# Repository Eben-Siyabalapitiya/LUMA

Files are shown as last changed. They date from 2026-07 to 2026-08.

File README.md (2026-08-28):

# LUMA 

A tiny desk robot I built that actually has a personality. Runs on an ESP32, shows animated eyes on a 1.8" TFT screen, and reacts to how you touch it. It also pulls live weather, keeps time, and has a calendar, all sitting on your desk just vibing.

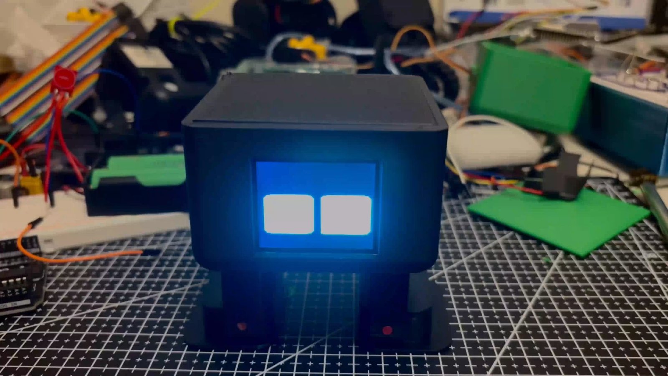
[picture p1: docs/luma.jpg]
LUMA on my desk


I made LUMA because my desk felt empty and I randomly got the urge to build a robot. That was pretty much the whole reason.

---

## What it does

LUMA has four screens you cycle through by tapping a touch sensor:

- **Face mode** : animated robot eyes that blink, look around, and randomly switch expressions
- **Clock** : clean digital clock synced over WiFi via NTP
- **Weather** : live temp, condition, humidity, and wind from OpenWeatherMap
- **Calendar** : full month grid with event highlights and floating particles in the background

The second touch sensor controls emotions:

| Interaction | What happens | 
|---|---|
| Single tap | LUMA gets excited : big happy eyes, fast blinks |
| Spam tap (4+) | LUMA gets mad : flat angry red eyes, multiple variants |
| Hold ~1 second | LUMA gets cozy : drowsy droopy eyes, slow blinks |
| Leave it alone | Resets to default after 6 seconds |

Each emotion has multiple face variants picked using weighted random probabilities so you never see the exact same reaction twice. After 30 seconds of no interaction on any screen it automatically goes back to face mode.

---

## Libraries needed

Install all of these through Arduino IDE Library Manager:

- Adafruit GFX Library
- Adafruit ST7735 and ST7789 Library
- TFT_RoboEyes by Shourov Paul

---

## Quick setup

1. Clone this repo or download the ZIP
2. Open `LUMA_v3.ino` in Arduino IDE
3. Fill in your details at the top:

```cpp
const char* ssid       = "YOUR_WIFI";
const char* password   = "YOUR_PASSWORD";
const char* weatherKey = "YOUR_OPENWEATHER_KEY";
```

4. Select **ESP32 Dev Module** as your board
5. Upload

Get a free OpenWeather API key at [openweathermap.org](https://openweathermap.org) — new keys take up to 2 hours to activate so grab one early.

---

## Project Files

- [`LUMA_v3.ino`](LUMA_v3.ino) : the firmware
- [`BOM.csv`](BOM.csv) / [`BOM.md`](BOM.md) : full parts list with links and rough CAD prices
- [`docs/WIRING.md`](docs/WIRING.md) : wiring diagram plus a pin-by-pin table for the TFT and both touch sensors
- [`CAD/`](CAD/README.md) : the printed enclosure : STEP files for every part, the `LUMA_V3.3mf` print file, and the Onshape link

[meetluma.live](https://www.meetluma.live/) is the main hub for all of it : full parts list,
the wiring diagram with the visual schematic, the CAD files through Onshape, the 3MF print
files, and the step-by-step assembly guide.

---

## Full Build Guide

Parts list, wiring diagram, 3D files, step-by-step assembly, and everything else you need to build your own LUMA:

**[meetluma.live](https://www.meetluma.live/)**

---

## Stardance

Built for Hack Club Stardance : <https://stardance.hackclub.com/projects/14705>

---
## AI Usage
Used AI as a guide when things got overwhelming like when my firmware hit the flash limit and I had no idea where to start. It never built anything for me, just helped me figure out what was wrong when I was stuck. Everything was built and decided by me.

---

Built by Eben Siyabalapitiya

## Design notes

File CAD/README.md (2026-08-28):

# CAD

The LUMA enclosure was designed in Onshape.

## STEP files (the CAD model)

Exported from Onshape.

- `LUMA_ASSEMBLY.step` : the whole thing assembled
- `Brain.step` : main body that holds the ESP32 and screen
- `Top_cover.step` : lid
- `Legs.step` : the legs
- `Leg_Joint.step` : pin that joins the legs to the body
- `Feet.step` : the feet

## Print file

- `LUMA_V3.3mf` : print-ready, opens in Bambu Studio, PrusaSlicer or Cura with the plate and
  settings already set up. Single colour, no supports needed on the body.

## Source

Live Onshape document (public, view or make your own copy to change the fit, screen cutout,
base size, etc.):
<https://cad.onshape.com/documents/46f7879e5381e394e69948ae/w/efe1e75b1016428808b3d0a2/e/479ee3b72502e2ef5b15629c>

Same files and the full print/assembly walkthrough are on [meetluma.live](https://www.meetluma.live/build).

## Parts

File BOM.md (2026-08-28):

# Bill of Materials

Machine-readable version with links: [`BOM.csv`](BOM.csv).

Prices are what I actually see on Amazon.ca (Aug 2026), in CAD, before tax and shipping.
They move around a lot and everything is cheaper on AliExpress if you're willing to wait.

| Part | Qty | Amazon.ca price (CAD) |
|---|---|---|
| ESP32 dev board, WROOM-32, 30-pin, USB-C | 1 | ~$14 |
| DIYmalls 1.8" ST7735S TFT LCD (128x160 SPI) | 1 | ~$15 single, ~$21 for a 2-pack |
| TTP223 capacitive touch sensor | 2 | only sold in packs, ~$13 for 20 |
| 830-point solderless breadboard | 1 | ~$8 single, ~$13 for a 3-pack |
| Dupont jumper wires, 120 pcs (M-M / M-F / F-F) | 1 kit | ~$9 |
| USB-C data cable | 1 | ~$8 |
| ESP32 30-pin breakout board (optional, expands 1 GPIO to 2, easier than a breadboard) | 1 | ~$10, sold ~$19 for a 2-pack |

Rough totals:

- Core electronics (ESP32 + screen + touch sensors): **~$42-45**
- Add breadboard, jumper wires and a USB-C cable: **~$65-70**
- Most of the extras (breadboard, wires, cable) you probably already have.

You'll also need a bit of filament for the printed case and a free OpenWeatherMap API key.

Full parts list with links and the rest of the build guide: [meetluma.live](https://www.meetluma.live/).

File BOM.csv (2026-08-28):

Part | Qty | Unit Price CAD | Link | Notes
ESP32 dev board WROOM-32 (30-pin USB-C) | 1 | 14 | https://www.amazon.ca/dp/B0CHBMFJBQ | Main board. "ESP32 Dev Module" in Arduino IDE
DIYmalls 1.8" ST7735S TFT LCD 128x160 SPI | 1 | 15 | https://www.amazon.ca/dp/B0BFDQDGSQ | ~$21 for a 2-pack: https://www.amazon.ca/dp/B0C2HNVSWV
TTP223 capacitive touch sensor | 2 | 0.65 | https://www.amazon.ca/dp/B01D1D0FLG | Sold in packs, ~$13 for 20 (HiLetgo). Need 2
830-point solderless breadboard | 1 | 8 | https://www.amazon.ca/s?k=830+point+solderless+breadboard | ~$13 for a 3-pack (ELEGOO)
Dupont jumper wires 120 pcs (M-M / M-F / F-F) | 1 | 9 | https://www.amazon.ca/dp/B0HGB3P9WG | 20 cm length
USB-C data cable | 1 | 8 | https://www.amazon.ca/s?k=usb-c+data+cable | Power and flashing
ESP32 30-pin breakout board | 1 | 10 | https://www.amazon.ca/dp/B0CWL7TK7T | Optional. Expands 1 GPIO to 2, easier than a breadboard. ~$19 for a 2-pack

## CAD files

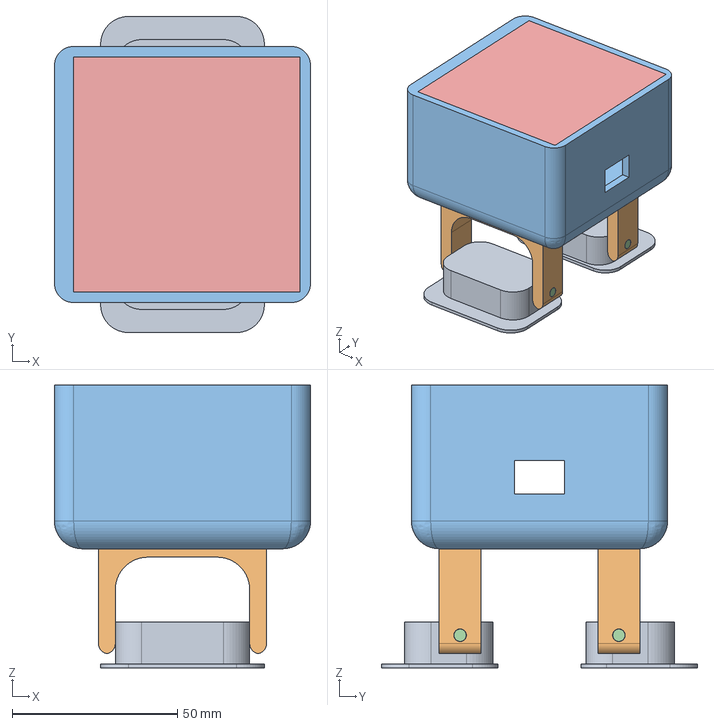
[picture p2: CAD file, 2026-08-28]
CAD/LUMA_ASSEMBLY.step
77.5 x 95.6 x 85.6 mm

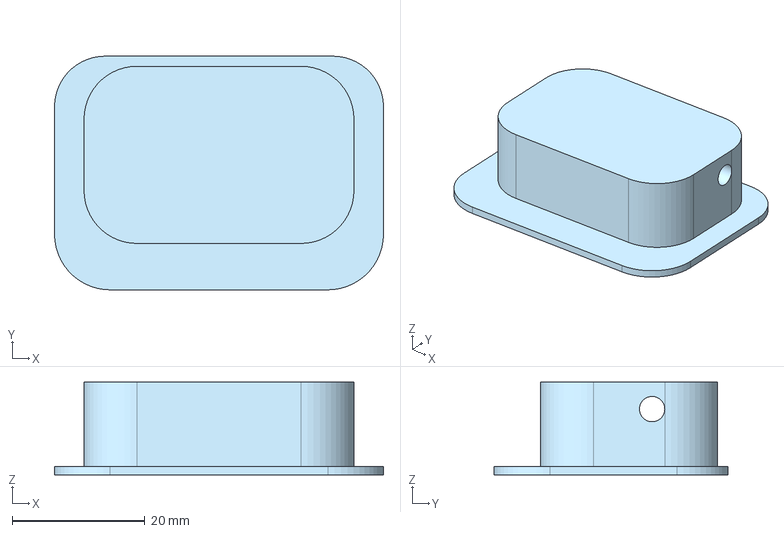
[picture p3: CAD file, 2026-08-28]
CAD/Feet.step
49.5 x 35.2 x 14.0 mm

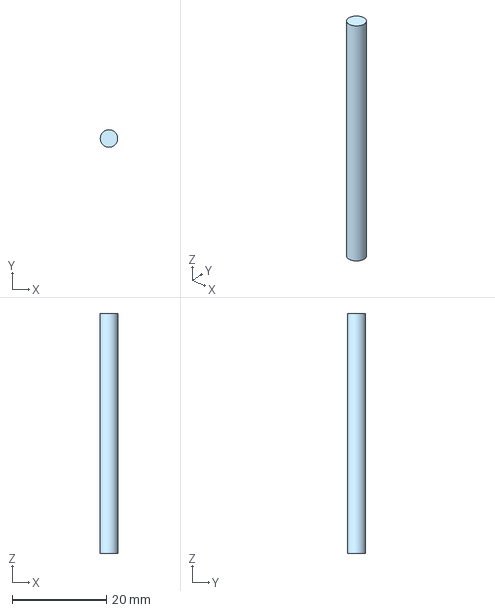
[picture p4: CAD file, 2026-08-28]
CAD/Leg_Joint.step
3.70 x 3.71 x 50.8 mm

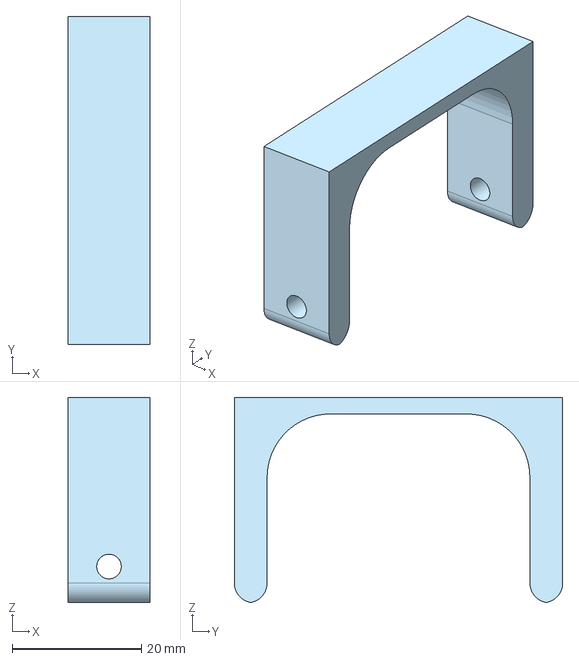
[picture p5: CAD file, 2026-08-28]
CAD/Legs.step
12.7 x 50.8 x 31.7 mm

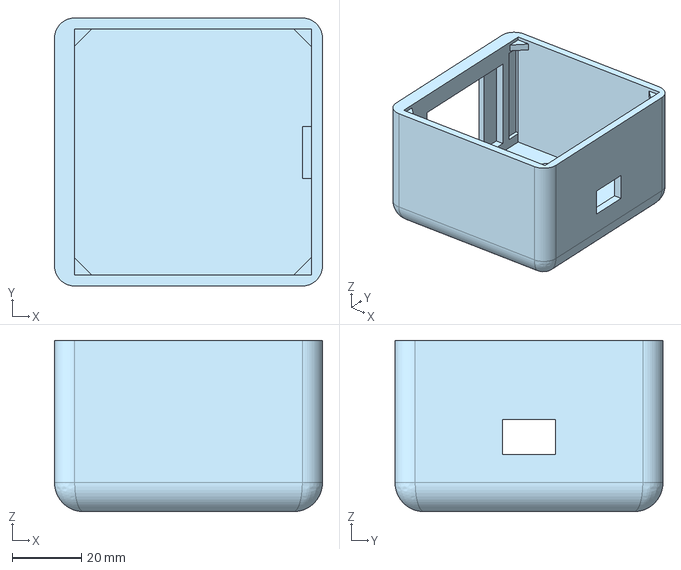
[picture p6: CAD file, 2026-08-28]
CAD/Brain.step
77.5 x 77.5 x 49.5 mm

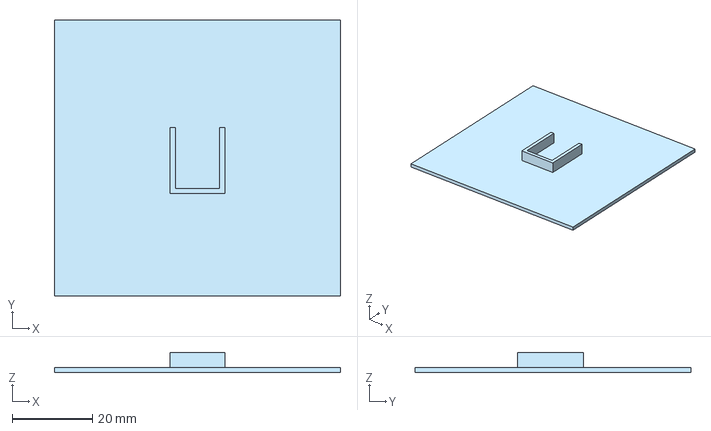
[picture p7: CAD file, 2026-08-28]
CAD/Top_cover.step
71.1 x 68.6 x 5.08 mm

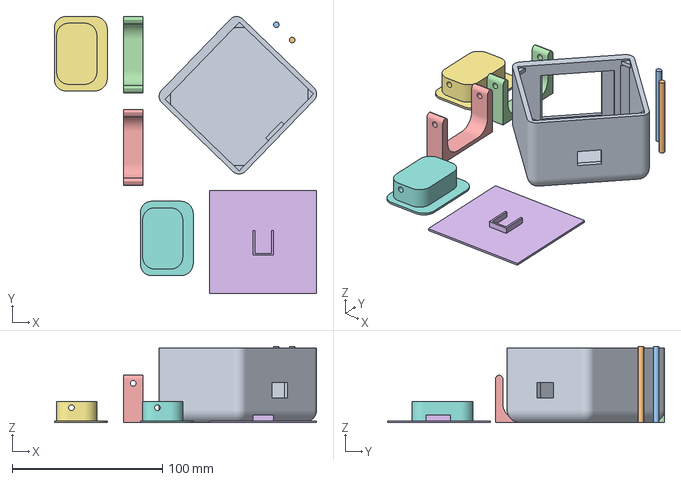
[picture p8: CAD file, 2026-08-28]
CAD/LUMA_V3.3mf
174.3 x 184.2 x 50.8 mm

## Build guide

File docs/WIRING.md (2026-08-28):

# Wiring

Pin numbers match the `#define`s at the top of [`LUMA_v3.ino`](../LUMA_v3.ino). The TFT runs
on the ESP32's default hardware SPI pins.

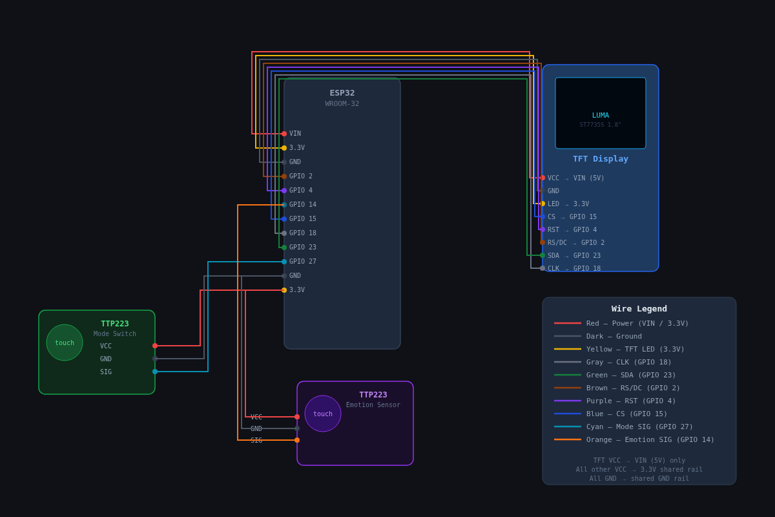
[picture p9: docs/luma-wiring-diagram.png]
LUMA wiring diagram


The tables below are the same thing in text. Same diagram is on [meetluma.live](https://www.meetluma.live/build).

## 1.8" ST7735S TFT → ESP32

| TFT | ESP32 |
|---|---|
| VCC | 3V3 |
| GND | GND |
| SCL / SCLK | GPIO 18 |
| SDA / MOSI | GPIO 23 |
| RES | GPIO 4 |
| DC | GPIO 2 |
| CS | GPIO 15 |
| BLK | 3V3 |

Run it off 3V3, not 5V.

## Touch sensor 1 (screen switch) → ESP32

Cycles through the face / clock / weather / calendar screens.

| TTP223 | ESP32 |
|---|---|
| VCC | 3V3 |
| GND | GND |
| I/O | GPIO 27 |

## Touch sensor 2 (emotions) → ESP32

Tap, spam-tap, and hold for the different reactions.

| TTP223 | ESP32 |
|---|---|
| VCC | 3V3 |
| GND | GND |
| I/O | GPIO 14 |

All three parts share the ESP32's 3V3 and GND. An ESP32 breakout board makes that a lot
less annoying. To move a pin, just change the `#define` in the sketch.

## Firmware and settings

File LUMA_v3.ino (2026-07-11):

#include <WiFi.h>
#include <WiFiClient.h>
#include <time.h>
#include <Adafruit_GFX.h>
#include <Adafruit_ST7735.h>
#include <SPI.h>

#define ROBOEYES_TFT_MODE
#include <TFT_RoboEyes.h>

// WIFI SETUPE
const char* ssid     = "WIFI NAME";
const char* password = "WIFI PASS";

const char* weatherHost = "api.openweathermap.org";
const char* weatherCity = "Toronto";
const char* weatherKey  = "API KEY";

float currentTemp  = 0, feelsLike = 0, windSpeed = 0;
int   humidity     = 0;
char  currentCondition[16] = "";
bool  weatherLoaded = false, weatherLoading = false, lastWeatherLoaded_flag = false;

#define TFT_CS  15
#define TFT_DC   2
#define TFT_RST  4
#define SCREEN_W 160
#define SCREEN_H 128

Adafruit_ST7735 tft = Adafruit_ST7735(TFT_CS, TFT_DC, TFT_RST);
TFTRoboEyes<Adafruit_ST7735> eyes(tft);

// COLORS
#define C_BG      0x0841
#define C_CYAN    0x07FF
#define C_MAGENTA 0xF81F
#define C_YELLOW  0xFFE0
#define C_GREEN   0x07E0
#define C_ORANGE  0xFD20
#define C_WHITE   0xFFFF
#define C_DGRAY   0x2104
#define C_MGRAY   0x4208
#define C_RED     0xF800
#define C_LTCYAN  0x9FFF
#define C_PINK    0xFC18

// MODES
enum Mode { FACE, CLOCK, WEATHER, CALENDAR };
Mode mode = FACE;
unsigned long lastInteraction = 0;
const unsigned long IDLE_TIMEOUT = 30000;

// TOUCH PINS TOP AND BACK
#define TOUCH_SWITCH  27
#define TOUCH_EMOTION 14
bool lastSwitchTouch = false, lastEmotionTouch = false;

// EMOTION SYSTEM
enum Emotion { EMO_NONE, EMO_EXCITED, EMO_MAD, EMO_COZY };
Emotion currentEmotion = EMO_NONE;
unsigned long emoTimer = 0;

#define EMO_DURATION  6000
#define TAP_WINDOW     500
#define HOLD_MS        900
#define MAD_TAPS         4

unsigned long tapTimes[8];
uint8_t  tapCount  = 0;
unsigned long lastTapTime = 0;
unsigned long holdStart   = 0;
bool holdActive = false;
bool holdFired  = false;

uint8_t madVar = 0, excVar = 0, cozyVar = 0;

// TIMERS
unsigned long lastClockUpdate   = 0;
unsigned long lastWeatherUpdate = 0;
unsigned long lastCalParticle   = 0;
unsigned long lastAgendaTick    = 0;

// Particles Feature
struct Particle { int16_t x,y; int8_t vx,vy; uint8_t life; uint16_t color; };
#define NUM_P 10
Particle parts[NUM_P];
bool partsInited = false;

void initParticles(){
  for(int i=0;i<NUM_P;i++){
    parts[i]={int16_t(random(10,SCREEN_W-10)),int16_t(random(20,SCREEN_H-10)),
              int8_t(random(-2,3)),int8_t(random(-2,3)),uint8_t(random(20,80)),
              (i%3==0)?C_CYAN:(i%3==1)?C_MAGENTA:uint16_t(C_GREEN)};
  }
  partsInited=true;
}

void tickParticles(){
  for(int i=0;i<NUM_P;i++){
    tft.drawPixel(parts[i].x,parts[i].y,C_BG);
    parts[i].x+=parts[i].vx; parts[i].y+=parts[i].vy; parts[i].life--;
    if(!parts[i].life||parts[i].x<0||parts[i].x>=SCREEN_W||parts[i].y<0||parts[i].y>=SCREEN_H){
      parts[i]={int16_t(random(10,SCREEN_W-10)),int16_t(random(30,SCREEN_H-10)),
                int8_t(random(-2,3)),int8_t(random(-2,3)),uint8_t(random(30,80)),parts[i].color};
    }
    tft.drawPixel(parts[i].x,parts[i].y,parts[i].color);
  }
}


void gradLine(int16_t x0,int16_t y,int16_t x1,uint16_t c1,uint16_t c2){
  int len=x1-x0; if(len<=0)return;
  uint8_t r1=(c1>>11)&31,g1=(c1>>5)&63,b1=c1&31;
  uint8_t r2=(c2>>11)&31,g2=(c2>>5)&63,b2=c2&31;
  for(int i=0;i<=len;i++){
    tft.drawPixel(x0+i,y,
      uint16_t((r1+(r2-r1)*i/len)<<11)|
      uint16_t((g1+(g2-g1)*i/len)<<5)|
      uint16_t(b1+(b2-b1)*i/len));
  }
}

void drawHeader(const __FlashStringHelper* lbl, uint16_t accent){
  tft.fillRect(0,0,SCREEN_W,20,C_BG);
  gradLine(0,0,SCREEN_W-1,accent,C_MAGENTA);
  gradLine(0,1,SCREEN_W-1,accent,C_MAGENTA);
  tft.setTextColor(C_WHITE); tft.setTextSize(1);
  int tw=strlen_P(reinterpret_cast<const char*>(lbl))*6;
  tft.setCursor((SCREEN_W-tw)/2,7); tft.print(lbl);
  tft.fillCircle(SCREEN_W-6,10,3,(WiFi.status()==WL_CONNECTED)?C_GREEN:C_RED);
}

void applyEmotion();
void drawScreen();
void updateClock();
void updateWeather();
void updateCalendar();
void drawClockBase();
void drawWeatherBase();
void drawCalendarBase();
void drawWeatherContent();

uint8_t weightedPick(const uint8_t* weights, uint8_t count){
  uint8_t r = random(0, 100);
  uint8_t acc = 0;
  for(uint8_t i = 0; i < count; i++){
    acc += weights[i];
    if(r < acc) return i;
  }
  return count - 1;
}

void applyEmotion(){
  if(mode != FACE) return;

  // always stop everything first
  eyes.setAutoblinker(false, 0, 0);
  eyes.setIdleMode(false, 0, 0);

  if(currentEmotion == EMO_MAD){
    // wide flat glare is like 30% tiny squint is like 25% slow disgusted 20%
    // big red stare 15% fast twitch blink 10%
    static const uint8_t madW[] = {30, 25, 20, 15, 10};
    uint8_t pick = weightedPick(madW, 5);
    while(pick == madVar) pick = weightedPick(madW, 5);
    madVar = pick;

    switch(madVar){
      case 0:
        // flat wide angry glare squished wide eyes
        eyes.setConfiguration(88, 28, 2, C_RED);
        eyes.setMood(ANGRY);
        eyes.setAutoblinker(false, 0, 0);
        break;
      case 1:
        // tiny squinted rage small narrow eyes
        eyes.setConfiguration(42, 18, 3, C_RED);
        eyes.setMood(ANGRY);
        eyes.setAutoblinker(false, 0, 0);
        break;
      case 2:
        // half closed disgusted droopy heavy lids
        eyes.setConfiguration(68, 22, 4, C_ORANGE);
        eyes.setMood(TIRED);
        eyes.setAutoblinker(false, 0, 0);
        break;
      case 3:
        // wide open psycho stare  big round angry
        eyes.setConfiguration(72, 68, 8, C_RED);
        eyes.setMood(ANGRY);
        eyes.setAutoblinker(false, 0, 0);
        break;
      case 4:
        // rapid irritated blink  normal size but fast twitch
        eyes.setConfiguration(65, 45, 5, C_RED);
        eyes.setMood(ANGRY);
        eyes.setAutoblinker(true, 0, 0);
        break;
    }

  } else if(currentEmotion == EMO_EXCITED){
    static const uint8_t excW[] = {30, 25, 20, 15, 10};
    uint8_t pick = weightedPick(excW, 5);
    while(pick == excVar) pick = weightedPick(excW, 5);
    excVar = pick;

    switch(excVar){
      case 0:
        // big round happy laugh
        eyes.setConfiguration(76, 72, 14, C_CYAN);
        eyes.setMood(HAPPY);
        eyes.setAutoblinker(true, 1, 1);
        eyes.anim_laugh();
        break;
      case 1:
        // wide open excited stare large eyes no blink
        eyes.setConfiguration(80, 70, 10, C_CYAN);
        eyes.setMood(HAPPY);
        eyes.setAutoblinker(false, 0, 0);
        break;
      case 2:
        //tiny cute happy
        eyes.setConfiguration(50, 50, 14, C_YELLOW);
        eyes.setMood(HAPPY);
        eyes.setAutoblinker(true, 1, 0);
        break;
      case 3:
        // happy wiggle with normal size, idle looking around
        eyes.setConfiguration(70, 60, 10, C_CYAN);
        eyes.setMood(HAPPY);
        eyes.setAutoblinker(true, 2, 1);
        eyes.setIdleMode(true, 1, 1);
        break;
      case 4:
        // laugh with wide eyes
        eyes.setConfiguration(74, 64, 8, C_YELLOW);
        eyes.setMood(HAPPY);
        eyes.anim_laugh();
        eyes.setAutoblinker(true, 2, 2);
        break;
    }

  } else if(currentEmotion == EMO_COZY){
    // drowsy half closed 40%, warm round happy 30%,
    // tiny sleepy 20%, soft neutral slow blink 10%
    static const uint8_t cozyW[] = {40, 30, 20, 10};
    uint8_t pick = weightedPick(cozyW, 4);
    while(pick == cozyVar) pick = weightedPick(cozyW, 4);
    cozyVar = pick;

    switch(cozyVar){
      case 0:
        // drowsy flat wide barely-open eyes
        eyes.setConfiguration(74, 22, 5, C_LTCYAN);
        eyes.setMood(TIRED);
        eyes.setAutoblinker(true, 7, 4);
        eyes.setIdleMode(false, 0, 0);
        break;
      case 1:
        //big happy eyes slow blink
        eyes.setConfiguration(64, 64, 16, C_PINK);
        eyes.setMood(HAPPY);
        eyes.setAutoblinker(true, 5, 3);
        eyes.setIdleMode(true, 4, 3);
        break;
      case 2:
        // tiny sleepy  small round eyes barely open
        eyes.setConfiguration(38, 20, 8, C_LTCYAN);
        eyes.setMood(TIRED);
        eyes.setAutoblinker(true, 9, 5);
        eyes.setIdleMode(false, 0, 0);
        break;
      case 3:
        // soft neutral medium eyes very slow gentle blink
        eyes.setConfiguration(60, 52, 12, C_CYAN);
        eyes.setMood(DEFAULT);
        eyes.setAutoblinker(true, 8, 6);
        eyes.setIdleMode(true, 6, 4);
        break;
    }
  }
}
void resetToDefault(){
  eyes.setConfiguration(70, 60, 10, C_CYAN); // reset eye shape
  eyes.setMood(DEFAULT);
  eyes.setAutoblinker(true, 3, 2);
  eyes.setIdleMode(true, 2, 2);
}

void handleEmotion(){
  bool touch = digitalRead(TOUCH_EMOTION);
  unsigned long now = millis();

  if(touch && !lastEmotionTouch){
    holdStart  = now;
    holdActive = true;
    holdFired  = false;
  }
  if(!touch) holdActive = false;

  if(holdActive && !holdFired && (now - holdStart >= HOLD_MS)){
    holdFired      = true;
    holdActive     = false;
    tapCount       = 0;
    currentEmotion = EMO_COZY;
    emoTimer       = now;
    applyEmotion();
  }

  if(touch && !lastEmotionTouch && !holdFired){
    if(now - lastTapTime > TAP_WINDOW * 3) tapCount = 0;
    if(tapCount < 8) tapTimes[tapCount++] = now;
    lastTapTime = now;
  }

  if(!touch && tapCount > 0 && (now - lastTapTime > 350) && !holdFired){
    if(tapCount >= MAD_TAPS){
      currentEmotion = EMO_MAD;
      emoTimer       = now;
      applyEmotion();
    } else if(tapCount == 1){
      currentEmotion = EMO_EXCITED;
      emoTimer       = now;
      applyEmotion();
    }
    tapCount = 0;
  }

  lastEmotionTouch = touch;

  if(currentEmotion != EMO_NONE && (now - emoTimer > EMO_DURATION)){
    currentEmotion = EMO_NONE;
    if(mode == FACE) resetToDefault();
  }
}

void handleSwitchTouch(){
  bool touch = digitalRead(TOUCH_SWITCH);
  static unsigned long lastPress = 0;
  unsigned long now = millis();
  if(touch && !lastSwitchTouch && now - lastPress > 300){
    mode = (Mode)((mode + 1) % 4);
    lastInteraction = now;
    partsInited = false;
    lastWeatherLoaded_flag = false;
    lastClockUpdate = 0;
    drawScreen();
    lastPress = now;
    if(mode == FACE && currentEmotion != EMO_NONE) applyEmotion();
    else if(mode == FACE) resetToDefault();
  }
  lastSwitchTouch = touch;
}

void checkIdle(){
  if(mode != FACE && millis() - lastInteraction > IDLE_TIMEOUT){
    mode = FACE;
    drawScreen();
    if(currentEmotion != EMO_NONE) applyEmotion();
    else resetToDefault();
  }
}

float jsonFloat(const char* buf, const char* key){
  const char* p = strstr(buf, key); if(!p) return 0;
  p = strchr(p, ':'); if(!p) return 0; return atof(p + 1);
}
void jsonStr(const char* buf, const char* key, char* out, int maxlen){
  const char* p = strstr(buf, key);
  if(!p){out[0]=0;return;}
  p = strchr(p, ':'); if(!p){out[0]=0;return;}
  p++; while(*p=='"'||*p==' ') p++;
  int i=0; while(*p&&*p!='"'&&*p!=','&&*p!='}'&&i<maxlen-1) out[i++]=*p++;
  out[i]=0;
}

void fetchWeather(){
  if(WiFi.status() != WL_CONNECTED) return;
  weatherLoading = true;
  WiFiClient client;
  if(!client.connect(weatherHost, 80)){weatherLoading=false;return;}
  client.print(F("GET /data/2.5/weather?q="));
  client.print(weatherCity);
  client.print(F("&units=metric&appid="));
  client.print(weatherKey);
  client.println(F(" HTTP/1.0"));
  client.print(F("Host: ")); client.println(weatherHost);
  client.println(F("Connection: close"));
  client.println();
  unsigned long t = millis();
  while(client.connected() && millis()-t < 8000){if(client.available()) break; delay(10);}
  while(client.available()){String ln = client.readStringUntil('\n'); if(ln=="\r") break;}
  static char body[512]; int idx = 0;
  while(client.available() && idx < 511) body[idx++] = (char)client.read();
  body[idx] = 0; client.stop();
  if(idx > 10){
    currentTemp = jsonFloat(body, "\"temp\"");
    feelsLike   = jsonFloat(body, "\"feels_like\"");
    humidity    = (int)jsonFloat(body, "\"humidity\"");
    windSpeed   = jsonFloat(body, "\"speed\"");
    jsonStr(body, "\"main\"", currentCondition, 16);
    weatherLoaded = true;
  }
  weatherLoading = false;
}

// SETUPPPP
void setup(){
  Serial.begin(115200);
  randomSeed(micros());
  pinMode(TOUCH_SWITCH, INPUT);
  pinMode(TOUCH_EMOTION, INPUT);
  tft.initR(INITR_BLACKTAB);
  tft.setRotation(3);
  tft.fillScreen(C_BG);
  eyes.begin(SCREEN_W, SCREEN_H, 50);
  eyes.setDisplayColors(C_BG, C_CYAN);
  eyes.setConfiguration(70, 60, 10, C_CYAN);
  resetToDefault();
  WiFi.begin(ssid, password);
  unsigned long s = millis();
  while(WiFi.status() != WL_CONNECTED && millis()-s < 10000) delay(200);
  configTime(-5 * 3600, 0, "pool.ntp.org");
  drawScreen();
}


void loop(){
  handleSwitchTouch();
  handleEmotion();
  checkIdle();
  if(mode == FACE)     eyes.update();
  if(mode == CLOCK)    updateClock();
  if(mode == WEATHER)  updateWeather();
  if(mode == CALENDAR) updateCalendar();
}

// SCREEN ROUTER

void drawScreen(){
  tft.fillScreen(C_BG);
  if(mode == FACE)     { resetToDefault(); }
  if(mode == CLOCK)    drawClockBase();
  if(mode == WEATHER)  drawWeatherBase();
  if(mode == CALENDAR) drawCalendarBase();
}

// CLOCK 

static uint8_t prevS = 255, prevM = 255, prevH = 255;

void drawClockBase(){
  tft.fillScreen(C_BG);
  drawHeader(F("// LUMA"), C_CYAN);
  tft.drawRoundRect(8, 24, SCREEN_W-16, 56, 6, C_DGRAY);
  tft.drawFastHLine(8, 88, SCREEN_W-16, C_DGRAY);
  prevS = prevM = prevH = 255;
}

void updateClock(){
  if(millis() - lastClockUpdate < 500) return;
  lastClockUpdate = millis();
  struct tm ti;
  if(!getLocalTime(&ti)) return;
  uint8_t s = ti.tm_sec;
  uint8_t m = ti.tm_min;
  uint8_t h = ti.tm_hour;

  if(h != prevH || m != prevM){
    tft.fillRect(10, 26, SCREEN_W-20, 52, C_BG);
    char timeBuf[6];
    snprintf(timeBuf, sizeof(timeBuf), "%02d:%02d", h, m);
    tft.setTextSize(4);
    tft.setTextColor(C_CYAN);
    int tw = 5 * 6 * 4;
    tft.setCursor((SCREEN_W - tw) / 2, 32);
    tft.print(timeBuf);
    tft.setTextSize(1);
    tft.setTextColor(h >= 12 ? C_ORANGE : C_LTCYAN);
    tft.setCursor(SCREEN_W - 26, 26);
    tft.print(h >= 12 ? F("PM") : F("AM"));
    prevH = h;
    prevM = m;
  }

  if(s != prevS){
    int barX = 10, barY = 73, barW = SCREEN_W - 20;
    int filled = (barW * s) / 59;
    tft.fillRect(barX, barY, barW, 4, C_DGRAY);
    gradLine(barX, barY,   barX + filled, C_CYAN, C_MAGENTA);
    gradLine(barX, barY+1, barX + filled, C_CYAN, C_MAGENTA);
    gradLine(barX, barY+2, barX + filled, C_CYAN, C_MAGENTA);
    tft.fillRect(SCREEN_W-30, 60, 28, 10, C_BG);
    tft.setTextSize(1);
    tft.setTextColor(C_MAGENTA);
    tft.setCursor(SCREEN_W-28, 62);
    tft.print(F("ss:"));
    if(s < 10) tft.print('0');
    tft.print(s);
    prevS = s;
  }

  if(m != prevM || prevM == 255){
    tft.fillRect(8, 90, SCREEN_W-16, 30, C_BG);
    char dateBuf[16];
    strftime(dateBuf, sizeof(dateBuf), "%A", &ti);
    tft.setTextSize(1);
    tft.setTextColor(C_MGRAY);
    tft.setCursor(12, 92);
    tft.print(dateBuf);
    strftime(dateBuf, sizeof(dateBuf), "%d %B %Y", &ti);
    tft.setTextColor(C_WHITE);
    tft.setCursor(12, 104);
    tft.print(dateBuf);
    gradLine(8, 116, SCREEN_W-8, C_CYAN, C_MAGENTA);
  }
}

void drawWeatherIcon(int16_t cx, int16_t cy, const char* c){
  if(!strcmp(c,"Clear")){
    tft.fillCircle(cx,cy,8,C_YELLOW);
  } else if(!strcmp(c,"Clouds")){
    tft.fillCircle(cx-4,cy+2,6,C_MGRAY); tft.fillCircle(cx+4,cy+2,6,C_MGRAY);
    tft.fillCircle(cx,cy-2,7,C_WHITE);   tft.fillRect(cx-8,cy+2,16,6,C_WHITE);
  } else if(!strcmp(c,"Rain")||!strcmp(c,"Drizzle")){
    tft.fillCircle(cx-3,cy-2,5,C_MGRAY); tft.fillCircle(cx+3,cy-2,5,C_MGRAY);
    tft.fillRect(cx-6,cy-2,12,5,C_MGRAY);
    for(int i=-6;i<=6;i+=4) tft.drawLine(cx+i,cy+5,cx+i-2,cy+10,C_LTCYAN);
  } else if(!strcmp(c,"Thunderstorm")){
    tft.fillCircle(cx-3,cy-4,5,C_DGRAY); tft.fillCircle(cx+3,cy-4,5,C_DGRAY);
    tft.fillRect(cx-6,cy-4,12,5,C_DGRAY);
    tft.drawLine(cx+2,cy+2,cx-2,cy+7,C_YELLOW);
    tft.drawLine(cx-2,cy+7,cx+1,cy+7,C_YELLOW);
    tft.drawLine(cx+1,cy+7,cx-3,cy+12,C_YELLOW);
  } else if(!strcmp(c,"Snow")){
    tft.drawLine(cx,cy-9,cx,cy+9,C_WHITE);
    tft.drawLine(cx-8,cy,cx+8,cy,C_WHITE);
    tft.fillCircle(cx,cy,2,C_LTCYAN);
  } else {
    for(int i=-8;i<=8;i+=4) tft.drawLine(cx-9,cy+i,cx+9,cy+i,C_MGRAY);
  }
}

const char* condGlyph(const char* c){
  if(!strcmp(c,"Clear"))        return "CLEAR";
  if(!strcmp(c,"Clouds"))       return "CLOUDY";
  if(!strcmp(c,"Rain")||!strcmp(c,"Drizzle")) return "RAIN";
  if(!strcmp(c,"Thunderstorm")) return "STORM";
  if(!strcmp(c,"Snow"))         return "SNOW";
  if(!strcmp(c,"Mist")||!strcmp(c,"Fog")||!strcmp(c,"Haze")) return "FOGGY";
  return c;
}

void drawWeatherBase(){
  tft.fillScreen(C_BG);
  drawHeader(F("// WEATHER"), C_YELLOW);
  lastWeatherLoaded_flag = false;
}

void drawWeatherContent(){
  tft.fillRect(0,22,SCREEN_W,SCREEN_H-22,C_BG);
  if(weatherLoading){
    tft.setTextColor(C_MGRAY); tft.setTextSize(1); tft.setCursor(40,60); tft.print(F("Fetching...")); return;
  }
  if(!weatherLoaded){
    tft.setTextColor(C_RED); tft.setTextSize(1); tft.setCursor(30,60); tft.print(F("NO DATA")); return;
  }
  drawWeatherIcon(36,55,currentCondition);
  tft.drawFastVLine(72,26,80,C_MGRAY);
  uint16_t tc=(currentTemp>25)?C_ORANGE:(currentTemp>10)?C_YELLOW:(currentTemp>0)?C_LTCYAN:C_CYAN;
  tft.setTextColor(tc); tft.setTextSize(3); tft.setCursor(78,28);
  int ti2=(int)abs(currentTemp);
  if(currentTemp<0){tft.print('-'); tft.setCursor(90,28);}
  tft.print(ti2);
  int xo=78+(currentTemp<0?18:0)+(ti2>=10?36:18);
  tft.setTextSize(1); tft.setTextColor(C_WHITE);
  tft.setCursor(xo,28); tft.print('o'); tft.setCursor(xo,34); tft.print('C');
  tft.setTextColor(C_WHITE); tft.setTextSize(1); tft.setCursor(78,62); tft.print(condGlyph(currentCondition));
  tft.drawRect(76,74,82,48,C_DGRAY);
  tft.setTextColor(C_MGRAY);  tft.setCursor(80,78);  tft.print(F("FEELS"));
  tft.setTextColor(C_LTCYAN); tft.setCursor(116,78); tft.print((int)feelsLike); tft.print('C');
  tft.setTextColor(C_MGRAY);  tft.setCursor(80,90);  tft.print(F("HUMID"));
  tft.setTextColor(C_CYAN);   tft.setCursor(116,90); tft.print(humidity); tft.print('%');
  tft.setTextColor(C_MGRAY);  tft.setCursor(80,102); tft.print(F("WIND"));
  tft.setTextColor(C_GREEN);  tft.setCursor(116,102);tft.print((int)windSpeed); tft.print(F("m/s"));
  tft.setTextColor(C_MGRAY);  tft.setCursor(80,114); tft.print(weatherCity);
  int bw=map((int)constrain(currentTemp,-20,40),-20,40,0,70);
  tft.fillRect(2,120,70,5,C_DGRAY);
  for(int d=0;d<5;d++) gradLine(2,120+d,2+bw,C_CYAN,C_ORANGE);
}

void updateWeather(){
  bool need=(millis()-lastWeatherUpdate>600000)||!weatherLoaded;
  if(need){fetchWeather(); lastWeatherUpdate=millis(); lastWeatherLoaded_flag=false;}
  if(!lastWeatherLoaded_flag){lastWeatherLoaded_flag=true; drawWeatherContent();}
}

// =====================
// CALENDAR
// =====================
struct CalEv { uint8_t day; const char* label; uint16_t color; };
const CalEv evts[] PROGMEM = {
  { 1,"New month!",   C_YELLOW},
  { 4,"Coffee meetup",C_CYAN  },
  {10,"Code review",  C_GREEN },
  {15,"Mid-month",    C_ORANGE},
  {22,"Today",        C_MAGENTA},
  {25,"Deploy v2",    C_PINK  },
  {30,"Month end",    C_RED   },
};
const int N_EVT = sizeof(evts)/sizeof(evts[0]);

void drawCalGrid(){
  struct tm ti; bool ok=getLocalTime(&ti);
  int td=ok?ti.tm_mday:0, tw=ok?ti.tm_wday:0;
  int fw=(tw-((td-1)%7)+7)%7;
  char buf[16];
  if(ok) strftime(buf,sizeof(buf),"%B %Y",&ti); else strcpy(buf,"CALENDAR");
  tft.setTextColor(C_GREEN); tft.setTextSize(1);
  tft.setCursor((SCREEN_W-(int)strlen(buf)*6)/2,22); tft.print(buf);
  const char* dn[]={"S","M","T","W","T","F","S"};
  int cw=SCREEN_W/7;
  for(int i=0;i<7;i++){
    tft.setTextColor((i==0||i==6)?C_ORANGE:C_MGRAY);
    tft.setCursor(i*cw+2,32); tft.print(dn[i]);
  }
  gradLine(0,40,SCREEN_W-1,C_GREEN,C_CYAN);
  int day=1,row=0,col=fw;
  while(day<=31&&row<6){
    int x=col*cw, y=44+row*14;
    if(y>SCREEN_H-18) break;
    bool isTd=(day==td), isWk=(col==0||col==6);
    uint16_t ec=0;
    for(int e=0;e<N_EVT;e++) if(pgm_read_byte(&evts[e].day)==(uint8_t)day){ec=pgm_read_word(&evts[e].color);break;}
    if(isTd){tft.fillRect(x,y-1,cw-1,12,C_MAGENTA); tft.setTextColor(C_BG);}
    else if(ec){tft.fillRect(x,y-1,cw-1,12,C_DGRAY); tft.setTextColor(ec);}
    else tft.setTextColor(isWk?C_ORANGE:C_WHITE);
    tft.setTextSize(1); tft.setCursor(x+(day<10?3:1),y); tft.print(day);
    col++; if(col>=7){col=0;row++;} day++;
  }
}

void drawCalendarBase(){
  tft.fillScreen(C_BG);
  drawHeader(F("// CALENDAR"),C_GREEN);
  if(!partsInited) initParticles();
  drawCalGrid();
}

void updateCalendar(){
  if(millis()-lastCalParticle>80){lastCalParticle=millis(); tickParticles();}
  if(millis()-lastAgendaTick>2000){
    lastAgendaTick=millis();
    struct tm ti; bool ok=getLocalTime(&ti);
    int td=ok?ti.tm_mday:0;
    tft.fillRect(0,SCREEN_H-16,SCREEN_W,16,C_BG);
    gradLine(0,SCREEN_H-17,SCREEN_W-1,C_GREEN,C_CYAN);
    int ni=-1;
    for(int e=0;e<N_EVT;e++) if(pgm_read_byte(&evts[e].day)>=(uint8_t)td){ni=e;break;}
    tft.setTextSize(1);
    if(ni>=0){
      int du=pgm_read_byte(&evts[ni].day)-td;
      tft.setTextColor(C_MGRAY); tft.setCursor(2,SCREEN_H-12);
      if(du==0) tft.print(F("TODAY: "));
      else{tft.print(F("IN ")); tft.print(du); tft.print(F("d: "));}
      tft.setTextColor(pgm_read_word(&evts[ni].color));
      tft.print(evts[ni].label);
    } else {
      tft.setTextColor(C_MGRAY); tft.setCursor(2,SCREEN_H-12); tft.print(F("No events"));
    }
  }
}

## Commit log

2026-06-25 Release LumaOS v3.0
    Fixed display orientation and wiring issues, improved screen navigation, added richer emotion reactions, upgraded the clock, weather, and calendar screens, improved touch sensor handling, and optimized the code to fit within ESP32 memory limits.
    [LUMA_v3.ino]
2026-07-06 Extra newline before resetToDefault function
    [LUMA_v3.ino]
2026-08-28 Add bill of materials
    Parts list with quantities and rough CAD prices, points to the site for buy links.
2026-08-28 Add wiring table under docs/
    TFT and both TTP223 sensors to the ESP32, pins matching the sketch. Visual schematic stays on the site.
2026-08-28 Add CAD folder with enclosure notes
    Onshape source and 3MF print files live on the site, model is parametric if you want to change the fit.
2026-08-28 Add Project Files section to README
    Points at the BOM, docs/, and CAD/ so everything is easy to find from the top.
2026-08-28 Use real Amazon.ca prices in BOM
    Swapped the placeholder prices for what parts actually cost on Amazon.ca right now.
2026-08-28 Add print-ready 3MF to CAD folder
    LUMA_V3.3mf (same file as the website) plus the public Onshape link in the README.
    [LUMA_V3.3mf]
2026-08-28 Add wiring diagram image to docs
    The actual schematic PNG from the site, embedded at the top of WIRING.md.
2026-08-28 Point README at the in-repo CAD and wiring files
2026-08-28 Add STEP files for the enclosure
    Onshape exports for all five enclosure parts (brain, top cover, legs, leg joint, feet).
    [Brain.step, Feet.step, Leg_Joint.step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]
2026-08-28 Add BOM.csv with purchase links
    CSV version in the root with Amazon.ca links, per the Highway submitting guide. BOM.md kept for readability.
    [BOM.csv]
2026-08-28 Add full assembly STEP
    LUMA_ASSEMBLY.step, the complete enclosure exported from Onshape as one file.
    [LUMA_ASSEMBLY.step]
